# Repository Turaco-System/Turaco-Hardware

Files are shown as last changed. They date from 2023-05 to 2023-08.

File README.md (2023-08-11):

# Turaco: An 8-Bit Open Source Games Console and Microcomputer

Turaco is a hybrid of an 80s style microcomputer, and an 8-bit games console. It is an open hardware system designed for retrocomputing, featuring a 50MHz eZ80 CPU, 1MB of built-in static RAM, the VERA graphics system, an expansion cartridge slot, SNES compatible gamepad ports, USB keyboard support, and a flexible development environment based on the C programming language implemented in the z88dk toolchain for Windows, macOS, and Linux/BSD.

Turaco is in the design stage. The goal is to produce a reference design and implementation which anyone can use to manufacture and sell Turaco systems.

The schematic is awaiting peer review, before being routed for fabrication and population. Pull requests and issue submission are actively encouraged.

## FAQ

Q: What is Turaco?

A: Turaco is an 8-bit programmable games console and microcomputer specifically designed for retro game development, with maximal performance and minimum price.

----

Q: What programming languages can be used with Turaco?

A: Turaco supports cross-development in both C and Z80 assembly language, with on-device programming languages in development.

----

Q: How much RAM does Turaco have?

A: Turaco has 1MB of on-board RAM, and supports RAM/ROM cartridges to expand the memory.

----

Q: What is the screen resolution and colour palette of Turaco?

A: Turaco has a screen resolution of 640x480 and supports 4096 colours.

----

Q: How many hardware sprites does Turaco support?

A: Turaco supports up to 128 hardware sprites.

----

Q: What audio capabilities does Turaco have?

A: Turaco has a 16-voice audio synthesizer and supports PCM audio sample playback.

----

Q: Is Turaco open source?

A: Yes, every aspect of Turaco, from hardware schematics to core system libraries, is open source.

----

Q: What controllers does Turaco use for games?
A: Turaco has two SNES compatible controller ports and supports USB keyboard input as well.

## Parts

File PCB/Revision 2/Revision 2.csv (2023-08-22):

Source: | /Users/kylecardoza/KiCAD/Turaco-Hardware/PCB/Revision 2/Revision 2.kicad_sch
Date: | 2023 August 11, Friday 11:42:13
Tool: | Eeschema 7.0.6-0
Generator: | /Applications/KiCad/KiCad.app/Contents/SharedSupport/plugins/bom_csv_grouped_by_value.py
Component Count: | 157
Collated Components:
Item | Qty | Reference(s) | Value | LibPart | Footprint | Datasheet | DNP
1 | 1 | BT1 | CR2032 | Turaco:Battery_Cell |  | ~
2 | 5 | C1, C2, C27, C31, C33 | 10µF | Turaco:C |  | ~
3 | 29 | C3, C4, C5, C6, C7, C8, C9, C10, C11, C12, C13, C14, C15, C16, C17, C22, C23, C24, C25, C26, C28, C29, C30, C32, C34, C35, C36, C37, C59 | 100nF | Turaco:C |  | ~
4 | 2 | C18, C19 | 10pF | Turaco:C |  | ~
5 | 8 | C20, C21, C47, C48, C49, C50, C53, C54 | 100nF | Turaco:C_Small |  | ~
6 | 1 | C38 | 3.3µF | Turaco:C |  | ~
7 | 1 | C39 | 4.7µF | Turaco:C |  | ~
8 | 1 | C40 | 2.2µF | Turaco:C_Small |  | ~
9 | 2 | C41, C42 | 1µF | Turaco:C_Small |  | ~
10 | 2 | C43, C44 | 2.7nF | Turaco:C_Small |  | ~
11 | 5 | C45, C46, C52, C55, C56 | 4.7µF | Turaco:C_Small |  | ~
12 | 1 | C51 | 4.7uF | Turaco:C_Small |  | ~
13 | 2 | C57, C58 | 10uF | Turaco:C_Small |  | ~
14 | 41 | D1, D2, D3, D4, D5, D6, D7, D8, D9, D10, D11, D12, D13, D14, D15, D16, D17, D18, D19, D20, D21, D22, D23, D24, D25, D26, D27, D28, D29, D30, D31, D32, D33, D34, D35, D36, D37, D38, D39, D40, D41 | ESD9B3.3ST5G | Diode:ESD9B3.3ST5G | Diode_SMD:D_SOD-923 | https://www.onsemi.com/pub/Collateral/ESD9B-D.PDF
15 | 1 | J1 | USB_C | Turaco:USB_C_Receptacle_PowerOnly_6P |  | https://www.usb.org/sites/default/files/documents/usb_type-c.zip
16 | 1 | J2 | SD_Card | Turaco:SD_Card |  | http://portal.fciconnect.com/Comergent//fci/drawing/10067847.pdf
17 | 1 | J3 | Conn_02x10_Odd_Even | Turaco:Conn_02x10_Odd_Even |  | ~
18 | 1 | J4 | Conn_02x10_Odd_Even | Turaco:Conn_02x10_Odd_Even |  | ~ | DNP
19 | 1 | J5 | Conn_02x03_Odd_Even | Turaco:Conn_02x03_Odd_Even |  | ~
20 | 1 | J6 | USB_A | Turaco:USB_A |  | ~
21 | 1 | J7 | HDMI_A | Turaco:HDMI_A |  | https://en.wikipedia.org/wiki/HDMI
22 | 1 | J8 | AudioJack | Turaco:AudioJack3 |  | ~
23 | 1 | J9 | Conn_02x32_Odd_Even | Turaco:Conn_02x32_Odd_Even |  | ~
24 | 3 | JP1, JP3, JP4 | SolderJumper_3_Bridged12 | Turaco:SolderJumper_3_Bridged12 |  | ~
25 | 1 | JP2 | SolderJumper_2_Open | Turaco:SolderJumper_2_Open |  | ~
26 | 3 | L1, L2, L3 | 600µH | Turaco:L |  | ~
27 | 1 | L4 | NRS4018T2R2MDGJ | Turaco:L |  | ~
28 | 2 | P1, P2 | ~ | Turaco:SNES_CONTROLLER
29 | 2 | R1, R2 | 5.1KΩ | Turaco:R |  | ~
30 | 1 | R26 | 33KΩ | Turaco:R |  | ~
31 | 1 | R27 | 510Ω | Turaco:R |  | ~
32 | 6 | R28, R29, R30, R31, R32, R33 | 47KΩ | Turaco:R |  | ~
33 | 1 | R36 | 10KΩ | Turaco:R |  | ~
34 | 2 | R37, R38 | 560Ω | Turaco:R_Small |  | ~
35 | 2 | R39, R40 | 47k | Turaco:R_Small |  | ~
36 | 1 | R41 | 1 | Turaco:R_Small |  | ~
37 | 8 | RN1, RN2, RN3, RN4, RN5, RN6, RN7, RN8 | 10KΩ | Device:R_Pack04_Split |  | ~
38 | 1 | U1 | LD39150DT33 | Turaco:LD39150DT33 | Package_TO_SOT_SMD:TO-252-3_TabPin2 | https://www.st.com/resource/en/datasheet/ld39150.pdf
39 | 1 | U2 | ~ | Turaco:eZ80F91
40 | 1 | U3 | 74CB3T1G125 | Turaco:74CB3T1G125 |  | http://www.ti.com/lit/sg/scyt129e/scyt129e.pdf
41 | 1 | U4 | ICE40UP5K-SG48ITR50 | Turaco:ICE40UP5K-SG48ITR50 | Package_DFN_QFN:QFN-48-1EP_7x7mm_P0.5mm_EP5.3x5.3mm
42 | 1 | U5 | TFP410PAP | Turaco:TFP410PAP | Package_QFP:HTQFP-64-1EP_10x10mm_P0.5mm_EP8x8mm_Mask4.4x4.4mm_ThermalVias | http://www.ti.com/lit/ds/symlink/tfp410.pdf
43 | 1 | U6 | AS7C38096A-10TIN | Turaco:AS7C38096A-10TIN | Package_SO:TSOP-II-44_10.16x18.41mm_P0.8mm
44 | 1 | U7 | 74LVC1G04 | Turaco:74LVC1G04 |  | https://www.ti.com/lit/ds/symlink/sn74lvc1g04.pdf
45 | 1 | U8 | ~ | Turaco:CH559T | Package_SO:SSOP-20_5.3x7.2mm_P0.65mm | https://kprasadvnsi.github.io/CH559_Doc_English/
46 | 1 | U9 | WM8524CGEDT | Turaco:WM8524CGEDT | Package_SO:TSSOP-16_4.4x5mm_P0.65mm
47 | 1 | U10 | AP3417CKTR-G1 | Turaco:AP3417CKTR-G1 | Package_TO_SOT_SMD:SOT-23-5
48 | 1 | U11 | 74LVC2G32 | 74xGxx:74LVC2G32 |  | http://www.ti.com/lit/sg/scyt129e/scyt129e.pdf
49 | 1 | X1 | CXO_SMD4 | Turaco:CXO_SMD4
50 | 1 | X2 | 32.768kHz | Turaco:Crystal |  | ~

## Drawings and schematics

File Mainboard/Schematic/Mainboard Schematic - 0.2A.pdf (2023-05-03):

## Address Bus

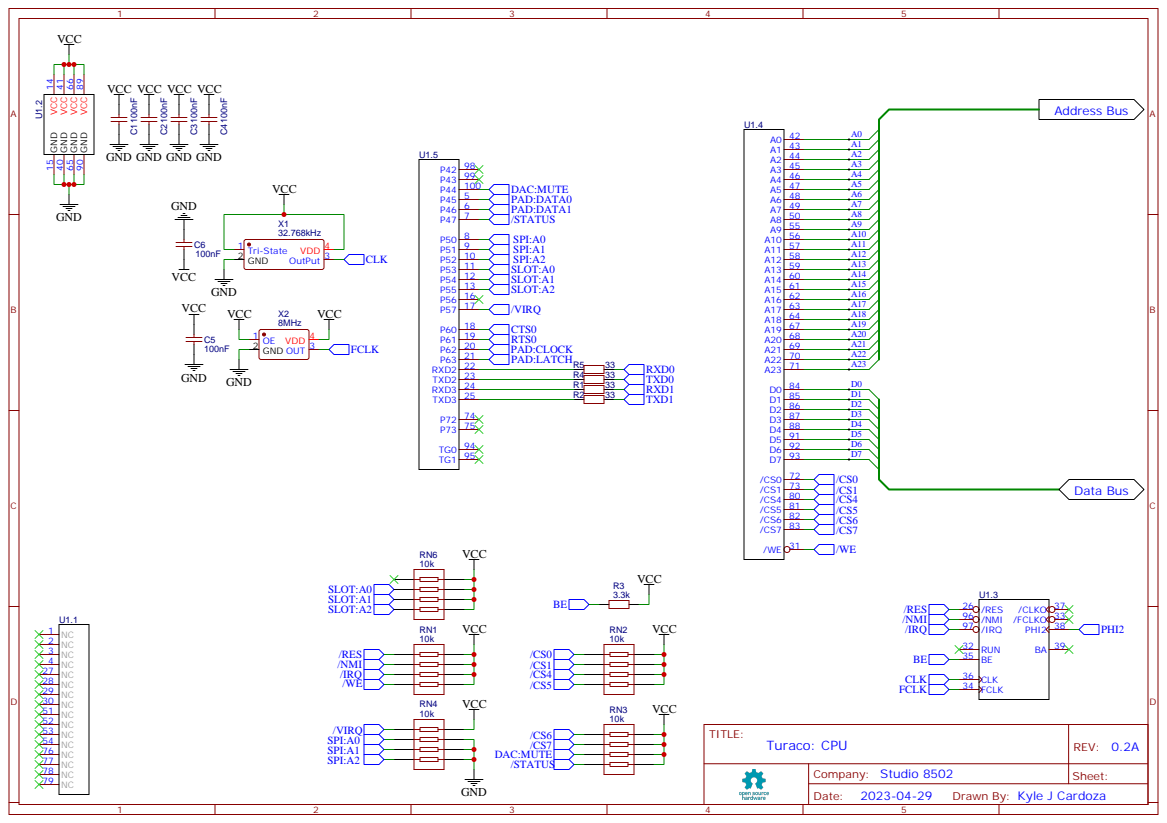
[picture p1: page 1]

Drawn By: Kyle J Cardoza

# Y5 10 Y4 11 Y3 12 Y2 13 Y1 14 Y0 15 VCC 16

# GND 100nF C³³

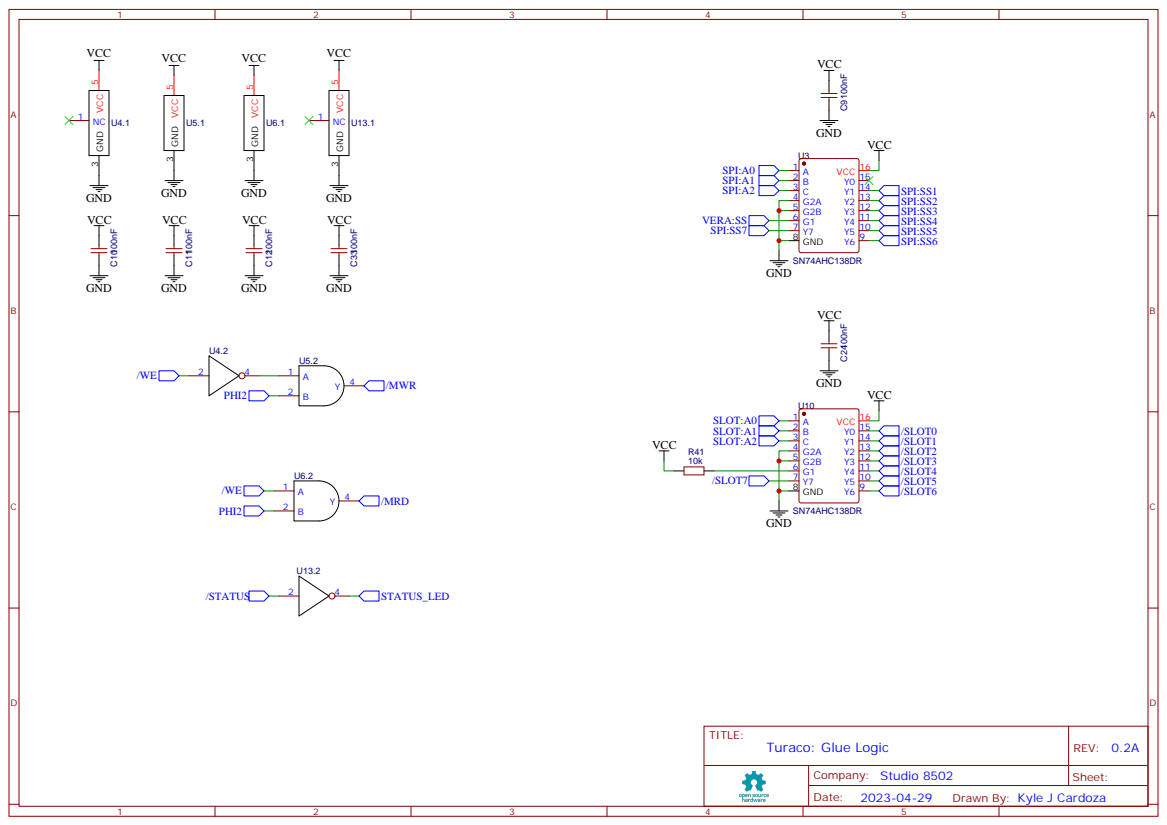
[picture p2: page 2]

## Address Bus

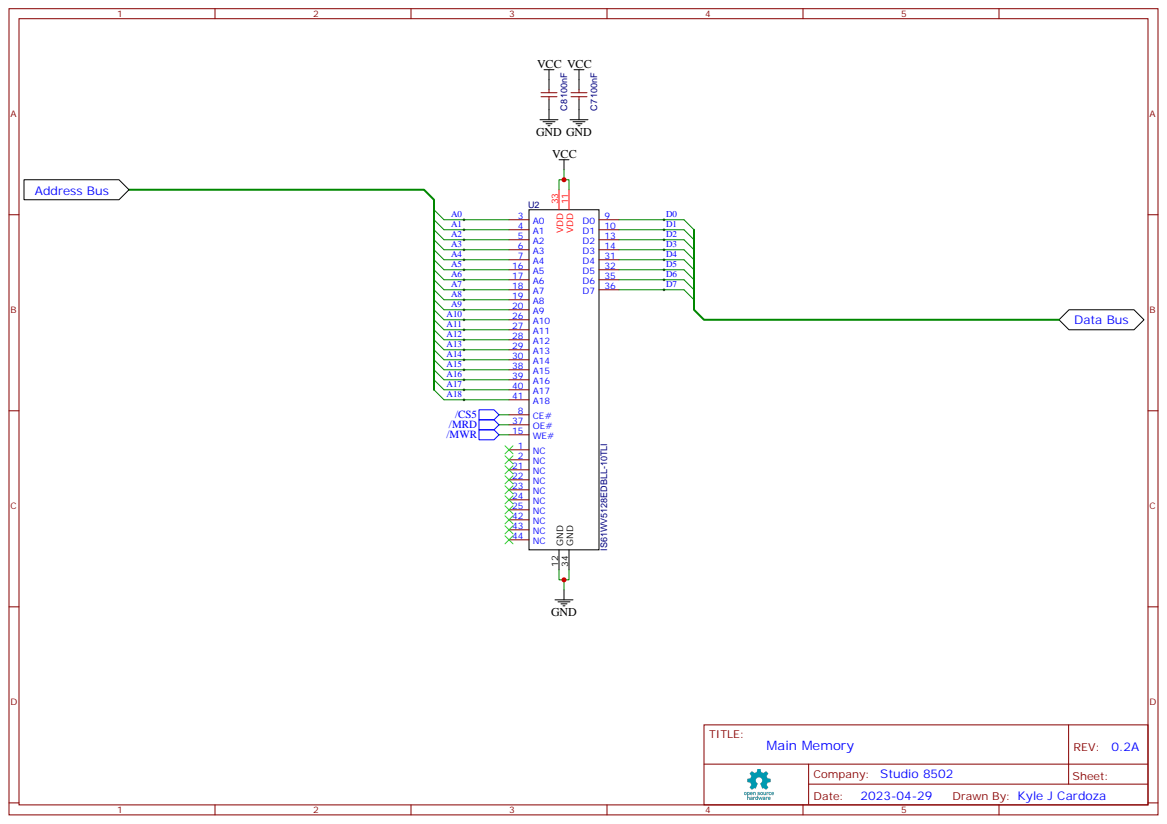
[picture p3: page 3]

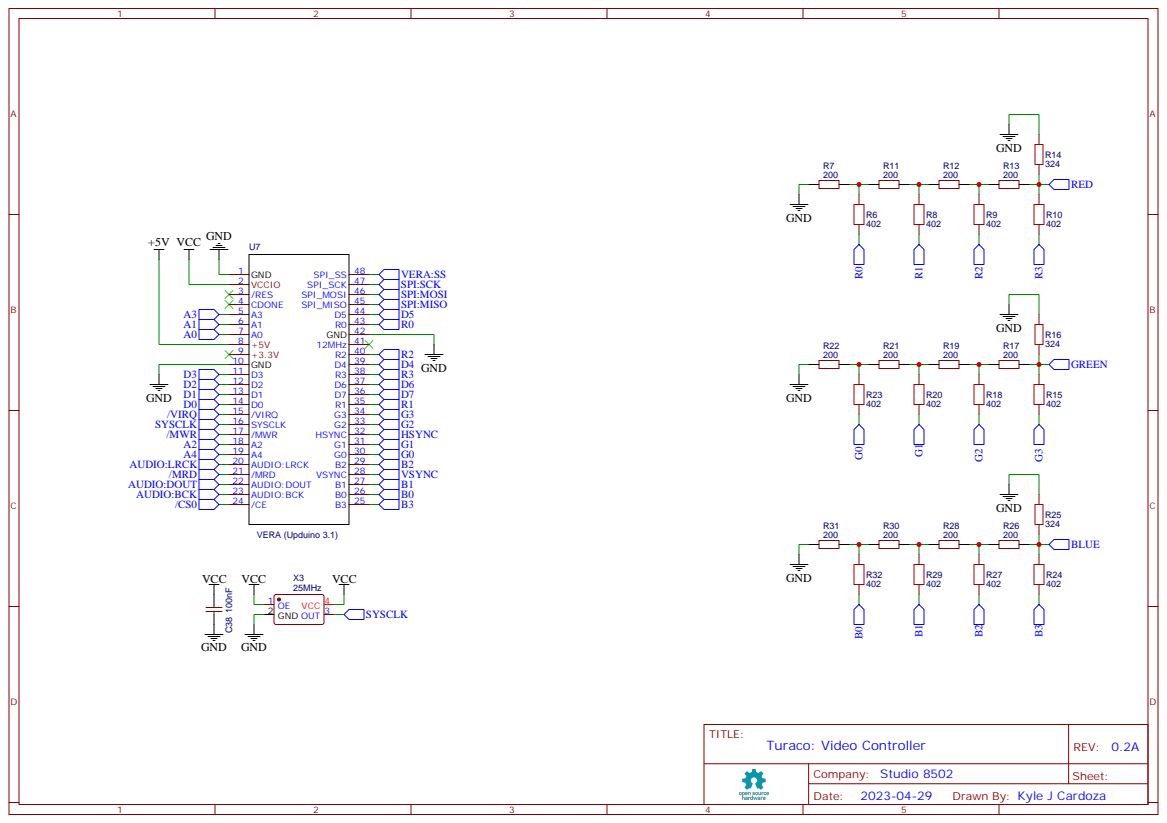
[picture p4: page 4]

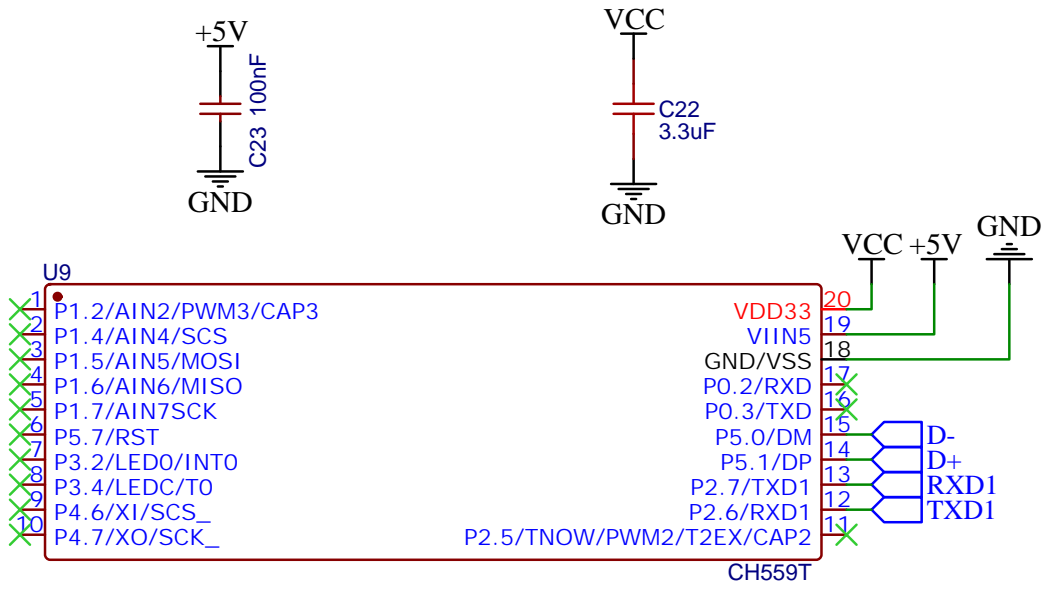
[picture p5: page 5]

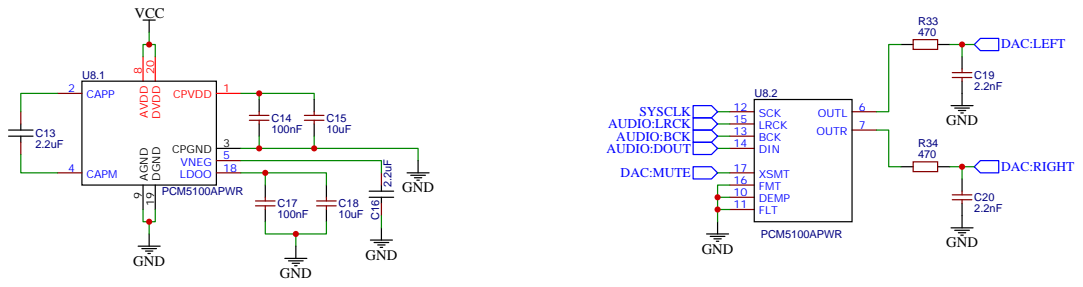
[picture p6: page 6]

## Address Bus

# D7 34 D6 33 D5 32 D4 31 D3 30 D2 29 D1 28 D0 27

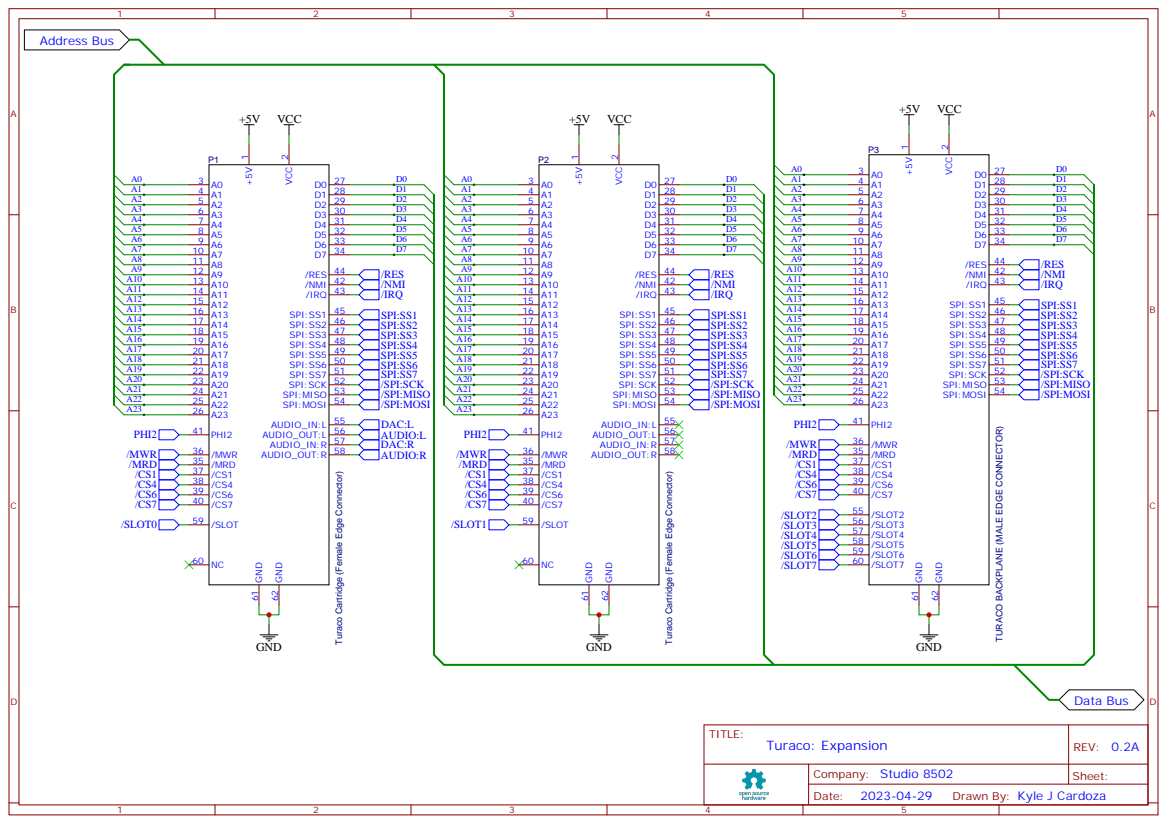
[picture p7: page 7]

SPI:MOSI 54 SPI:MISO 53 SPI:SCK 52 SPI:SS7 51 SPI:SS6 50 SPI:SS5 49 SPI:SS4 48 SPI:SS3 47 SPI:SS2 46 SPI:SS1 45

TURACO BACKPLANE (MALE EDGE CONNECTOR)

Turaco Cartridge (Female Edge Connector)

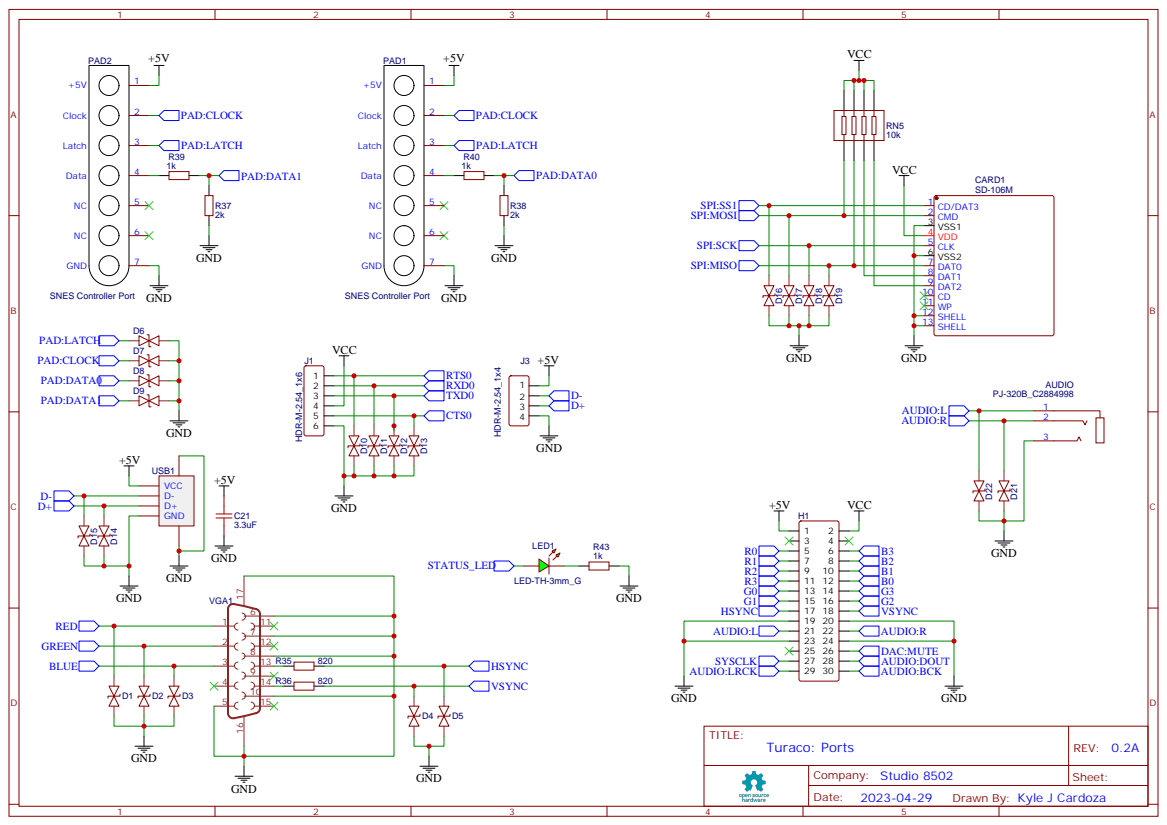
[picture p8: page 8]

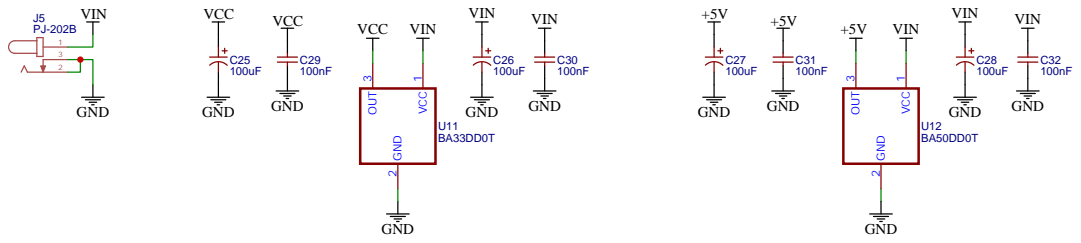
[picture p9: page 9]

GND GND GND GND

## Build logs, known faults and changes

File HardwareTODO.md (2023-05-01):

# Hardware TODO

A list, in no particular order, of changes or ideas relating to the Turaco hardware:

1. We should provide printable STLs and label templates for cartridges
2. We should design and provide a printable plastic console case

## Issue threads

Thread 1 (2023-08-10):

Where do IRQs 2-7 connect to the CPU?

tedchoward, 2023-08-10:
I see you have a Bus Alias named `Interrupts` that includes `~{IRQ}[0..7]`. I see on the schamatic where IRQ0 and IRQ1 connect to the CPU.

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

What I don't see are where the other IRQ lines connect to the CPU.

Or are there only 2 IRQ lines, and the alias is wrong?

Or am I missing something obvious?

KyleCardoza, 2023-08-11:
IRQs 2-7 have been subsumed into the GPIO port -- as each of the 16 pins on the GPIO port can be an IRQ source in its own right. The bus alias is a leftover from an earlier iteration. I'll go ahead and fix that now.

Closed 2023-08-22.

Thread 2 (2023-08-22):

Schematic Review

AdShea, 2023-08-22:
- Maybe add series resistors (10ohm?) to the transmit end of high-speed signals (SD card, RMII, I2S) to help reduce EMI and reflections on those signals.
- Add a Common-mode choke or ferrite beads to the audio jack on the DAC-side of the TVS diodes. (again, EMI. Also helps a bit with ESD/EFT too).
- Depending on what cap you're going to use for C2, you may run into issues with the 3.3V rail stability (look at Figure 15 and 16 of the
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
LD39150DT33 datasheet). Electrolytic may be ok, ceramic will probably be unstable.
- Toss a footprint on there for an I2C EEPROM? No need to populate it now, but never know if there will be some "per-board-tuning" needs that you don't want to worry about dealing with on the SD-card.

I'll keep poking into datasheets, but here's a start.

KyleCardoza, 2023-08-22:
Thank you for that.

KyleCardoza, 2023-08-22:
All but the I2C EEPROM are now in the schematic. I'm curious what the benefit of the I2C EEPROM might be over flashing to the EZ80F91's on-chip ROM from the SD card.

AdShea, 2023-08-23:
On chip ROM would work too. I'm guessing there's some way to clear from an external tool as well?

KyleCardoza, 2023-08-23:
Using the ZDI port, and an ESP-based adapter designed by the AGON project, it's possible to flash the EZ80 chip directly, yes.

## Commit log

2023-05-01 Added cartridge schematic
2023-05-01 Schematic fixes
2023-05-01 Updated schematic
2023-05-04 Updated mainboard schematic to 0.3A
2023-05-04 Update schematic and README
2023-05-17 Updated schematic and added label templates
2023-08-10 Catchup commit
    [Revision 2.kicad_pcb, Revision 2.kicad_sch, audio_dac.kicad_sch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]
2023-08-11 Work on the schematic continutes
    [cpu.kicad_sch, dvi_transmitter.kicad_sch, ethernet_header.kicad_sch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]
2023-08-11 ESD protection diodes go BRRRRRRR
    [audio_jack.kicad_sch, controllers.kicad_sch, ethernet_header.kicad_sch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]
2023-08-11 Removed extraneous IRQ entries from bus alias 'Interrupts'
    [cpu.kicad_sch, dvi_transmitter.kicad_sch, vera.kicad_sch]
2023-08-22 Updated re: issue #2
    [Revision 2.csv, Revision 2.kicad_sch, audio_dac.kicad_sch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]
